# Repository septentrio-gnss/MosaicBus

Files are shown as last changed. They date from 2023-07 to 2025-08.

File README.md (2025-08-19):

<p align="center">
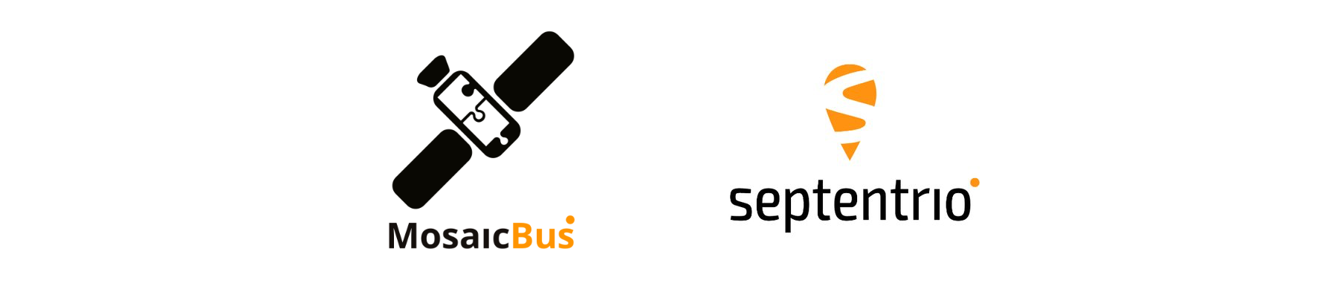
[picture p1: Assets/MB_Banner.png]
  
</p>

# MosaicBus

## What is the MosaicBus project?
**MosaicBus is a Septentrio Open-Source hardware project powered by the Mosaic GNSS receiver that is compatible with the Mikroe mikroBUS standard.**
The objective of this project was to allow easy prototyping and development with the Mosaic by using the mikroBUS ecosystem.

The board also has the option to be used as a standalone device by using the USB-C connector and MosaicBus has been designed to be used with either the Septentrio [**Mosaic-x5**](https://www.septentrio.com/en/products/gps/gnss-receiver-modules/mosaic-x5) or the [**Mosaic-H**](https://www.septentrio.com/en/products/gps/gnss-receiver-modules/mosaic-h).

<p align="center">
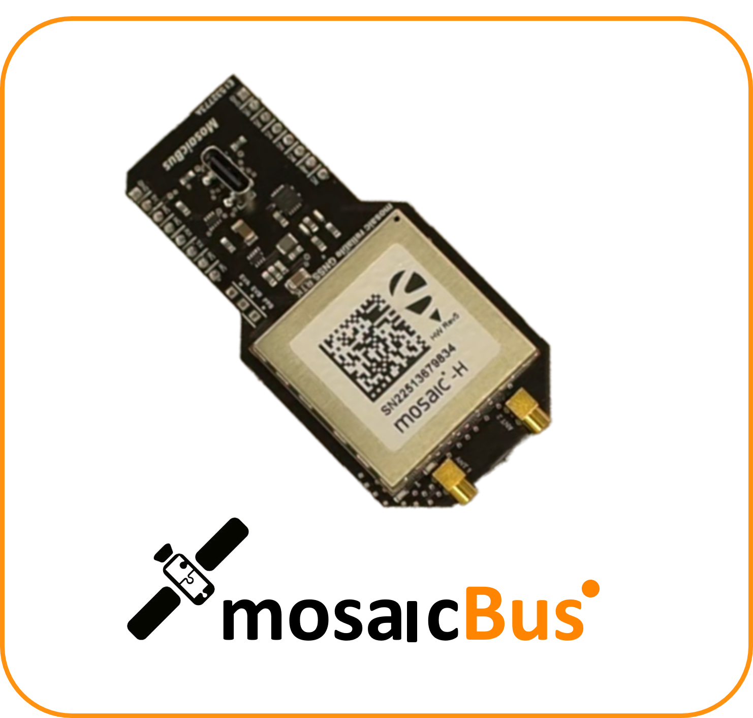
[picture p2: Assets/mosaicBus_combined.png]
  
</p>

## What is the Mosaic module?
**[Mosaic modules](https://web.septentrio.com/GH-SSN-modules) are Septentrio's small-size and low-power GNSS receiver modules ideal for providing highly accurate positions.** Mosaic modules integrate the latest generation of GNSS technology, delivering highly accurate positions with minimal power consumption. While compact in size they fully retain the high-reliability and exceptional accuracy performance that Septentrio receivers are known for. True multi-frequency multi-constellation technology gives our module receivers access to every possible signal from all available GNSS satellite constellations including the U.S. GPS, European Galileo, Russian GLONASS, as well BeiDou, QZSS and NavIC. [Septentrio’s advanced field-proven algorithms](https://www.septentrio.com/en/company/septentrio-gnss-technology) exploit this signal diversity to deliver maximum positioning availability and reference network compatibility.

## Can I buy this board?
### Similar board produced by MIKROE
While an exact version of this board cannot be bought today. A very similar board is now sold and distributed by MIKROE (MikroElektronika). MIKROE is a Serbian company known for its mikroBUS™ standard and Click board™ ecosystem, which simplify embedded development. In collaboration with Septentrio, they created the Mosaic Click board (originally using this project as an inspiration), integrating Septentrio’s mosaic-X5 GNSS module into the mikroBUS platform. This brings cm-level RTK positioning, anti-jamming/anti-spoofing resilience, and multi-constellation support to developers, enabling fast prototyping and easy integration of high-precision GNSS into applications ranging from hobby projects to robotics, IoT, and industrial systems.

You can purchase this Mikroe board here:
[**Mikroe mosaic Click board**](https://www.mikroe.com/mosaic-click)

<p align="center">
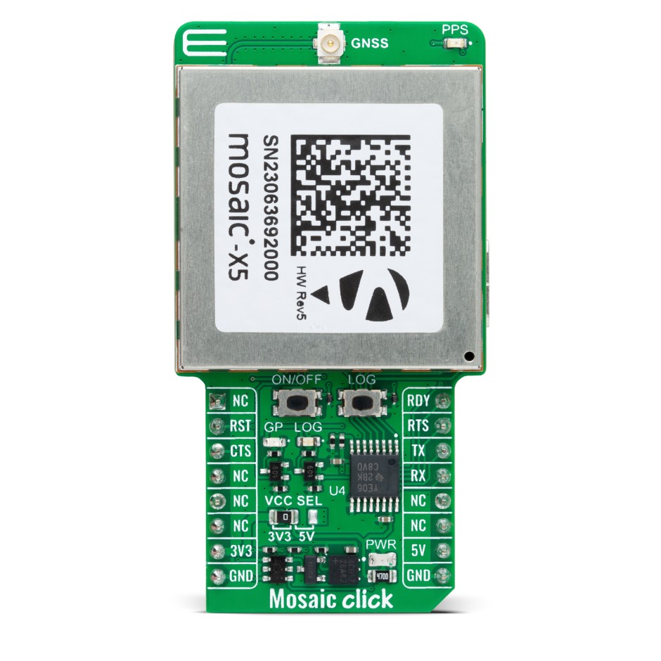
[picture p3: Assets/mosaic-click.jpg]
  
</p>

### Mikroe (and MosaicBus) boards usable with Movella XSense
Mikroe board (or a MosaicBus board), such as the Mosaic Click board, can bring high-precision GNSS into the Movella Xsens ecosystem, enabling seamless fusion of GNSS and inertial sensors. By pairing the Mosaic Click with Xsens’ MTi-series IMUs or GNSS/INS devices, users can achieve robust centimeter-level positioning with enhanced resilience against jamming and spoofing. This combination is ideal for applications in robotics, UAVs, autonomous systems, and industrial navigation, where accurate and reliable positioning depends on both inertial sensing and high-end GNSS. The boards, based on Mikroe’s mikroBUS™ standard, ensure easy integration and rapid prototyping, making them suitable for both research and commercial development.

You can get an evaluation kit from Movella XSense here:
[**Movella XSense mosaic eval kit**](https://www.movella.com/products/sensor-modules/xsens-mti-680-septentrio-mosaic-x5)
<p align="center">
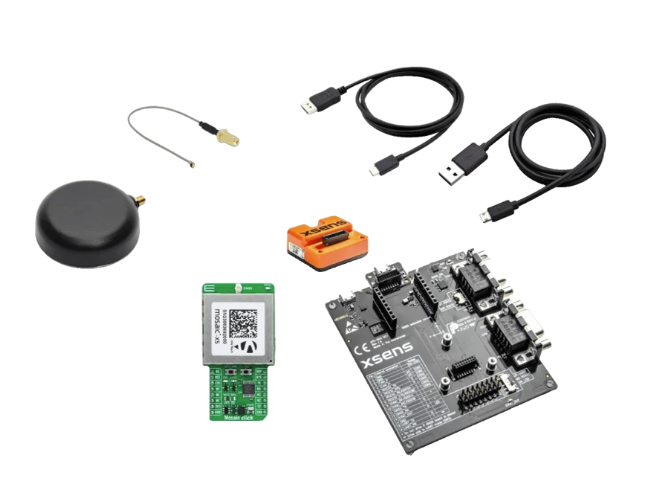
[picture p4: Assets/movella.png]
  
</p>

### Who is Septentrio?
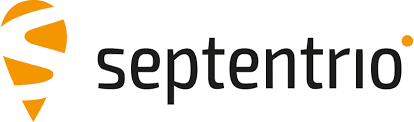
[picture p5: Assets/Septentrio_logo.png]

Septentrio designs, manufactures and sells high-precision, multi-frequency, multi-constellation GPS/GNSS equipment for use in demanding applications. Septentrio products are used in a wide variety of industries including marine, construction, precision agriculture, logistics, machine control, rail, automotive, survey and mapping, geographic information systems (GIS), unmanned aerial vehicles (UAVs) and scientific. Septentrio receivers deliver consistently accurate and precise GNSS positioning scalable to centimeter-level and designed to perform solidly in the most challenging environments. Septentrio receivers are available as OEM boards, housed receivers and smart antennas.

The technology offers high accuracy and reliability thanks to GNSS+ algorithms as well as <a href="https://www.septentrio.com/en/advanced-interference-monitoring-mitigation-aim">Septentrio's Advanced Interference Monitoring and Mitigation (AIM+)</a> which protects against RF interference (jamming) and spoofing.

For more information about Septentrio products go to [**https://www.septentrio.com/**](https://web.septentrio.com/GH-SSN-home).

## How to set up MosaicBus?
### Hardware
To start using the MosaicBus some antennas need to be connected to the board.
When using a [**Mosaic-x5**](https://www.septentrio.com/en/products/gps/gnss-receiver-modules/mosaic-x5) only a single antenna needs to be connected to the ANT 1 MMCX connector.
However when using the [**Mosaic-H**](https://www.septentrio.com/en/products/gps/gnss-receiver-modules/mosaic-h) a single or dual antenna setup can be configured.
To have a single antenna setup the antenna needs to be connected to the ANT 1 MMCX connector.
When using dual antennas the main antenna is connector to the ANT 1 MMCX connector while the auxillary is connected to the ANT 2 MMCX connector.

Afterwards just click the MosaicBus into a mikroBUS compatible carrier board.

The easiest way to configure the Mosaic is through the USB interface.
When connecting the MosaicBus with a computer through a USB-C cable. 
A new USB device should be visible on the system.
If the system is running Linux or MacOS, the drivers for the Mosaic are automatically installed.
When using a Windows system the drivers have to be installed manually.
These are contained on the new drive visible in file manager.
Running the installer is unnecessary when [**RxTools**](https://www.septentrio.com/en/products/gps-gnss-receiver-software/rxtools) is already installed.

## Interfaces on the MosaicBus
The MosaicBus is compliant with the mikroBUS standard.
<p align="center">
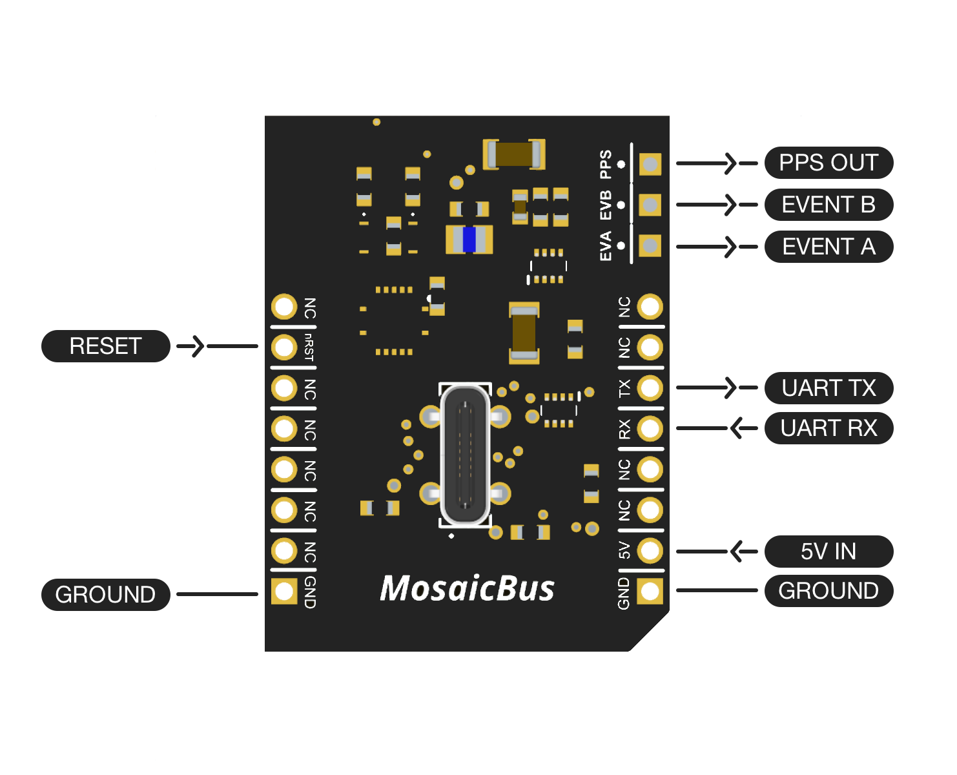
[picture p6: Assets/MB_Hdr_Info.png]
  
</p>

### Power
In order to power the board there are 2 options.
The first is to use the USB-C connector.
Another option is to use the +5V and ground pins.
This can be powered by any 5V DC supply.

### RESET
To reset the MosaicBus board the nRST pin can be pulled low.
This for example can be done by a GPIO pin or a button.

### COM port
To communicate with the Mosaic a **UART** connection is exposed.
This can be used with a serial reader or a microcontroller.
The following settings are required for this communication to take place.
| baud rate | data bits | stop bits | parity | flow control |
|:---:|:---:|:---:|:---:|:---:|
| 115200 | 8 | 1 | no | none |

On the Mosaic if some settings need to be changed, the ones for *COM3* are the ones exposed and should be edited.

### USB
#### Web interface
By default the Mosaic suppports **Ethernet-over-USB**. Therefore its possible to connect to the receiver and access its information and configuration through a browser.
To do so search to the static IP address which is [`192.168.3.1`]().
This will show the Mosaic's web interface where you can configure the Mosaic.

#### Command line
Another way to connect to the Mosaic receiver is using its COM ports.
These ports should be visible as [`ACM0`]() and [`ACM1`]().
Using a serial terminal such as Putty a connection can be established using the following settings.
| port | baud rate | data bits | stop bits | parity | flow control |
|:---:|:---:|:---:|:---:|:---:|:---:|
| ACM0 / ACM1 | 115200 | 8 | 1 | no | none |

Now you can interface using the command line.
For information on the commands, syntax and reponses the Mosaic Reference Guide section 3.1 can be consulted.

### Events
The MosaicBus has through hole pins which expose 2 event pins. **EVENT A** and **EVENT B**
These can be used to input a time-tagged signal with an accuracy of 20ns.
In turn this will output SBF with can include the position and/or time when the event occurs.
This can be configured using the **setEventParameters** command.

### PPS
The board also exposes a **PPS** output through hole pin.
The polarity, frequency and pulse width of this can be set with the **setPPSParameters** command.
The PPS signal uses 1.8V logic, but can be level-shifted to 3.3V logic if required.

### Antennas 
<p align="center">
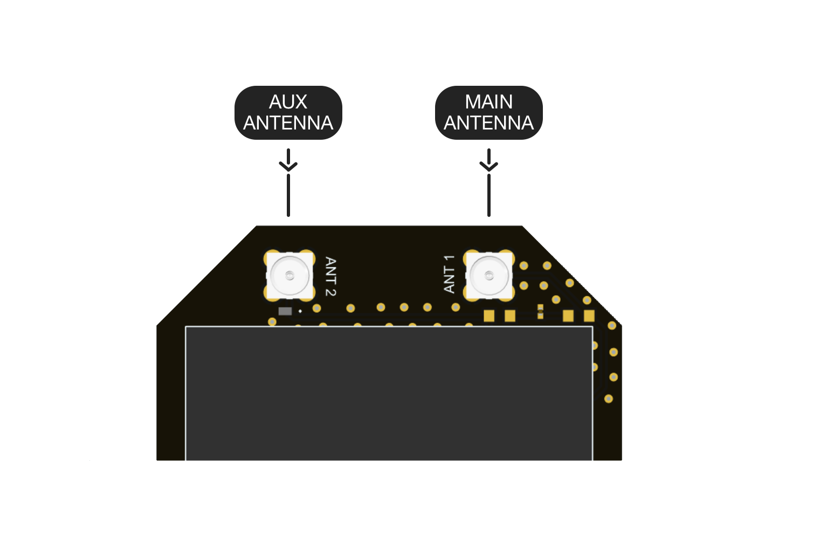
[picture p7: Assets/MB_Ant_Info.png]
  
</p>

The MosaicBus also has 1 or 2 antenna connectors available depending if you used the Mosaic-x5 or Mosaic-H model.
When using the [**Mosaic-x5**](https://www.septentrio.com/en/products/gps/gnss-receiver-modules/mosaic-x5) the **ANT 1** will be available to use.
When using the [**Mosaic-H**](https://www.septentrio.com/en/products/gps/gnss-receiver-modules/mosaic-h) both the **ANT 1** and **ANT 2** are available to provide dual heading.
*This has to be configured in the Mosaic*

## How to produce
All the files needed are each in their own folder, such as the BOM (Bill Of Materials), the Gerber and Pick-place files.

***Disclamer***
All the files are provided as is. These have not been fully validaded by the author or Septentrio.
The use of any of these files are at your own risk and responsibility.

---
*Designed by A. Gheeraert*

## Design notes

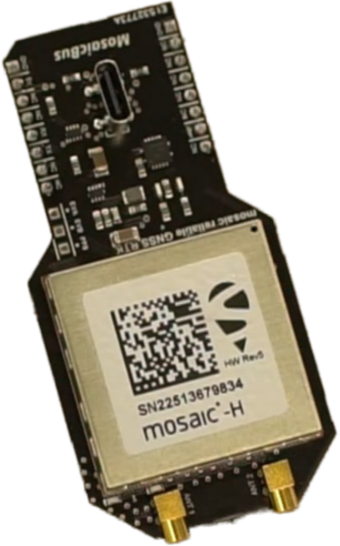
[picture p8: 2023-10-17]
Assets/design-b1985c28-233e-4ac5-8a65-0dd0d61b1b28.png

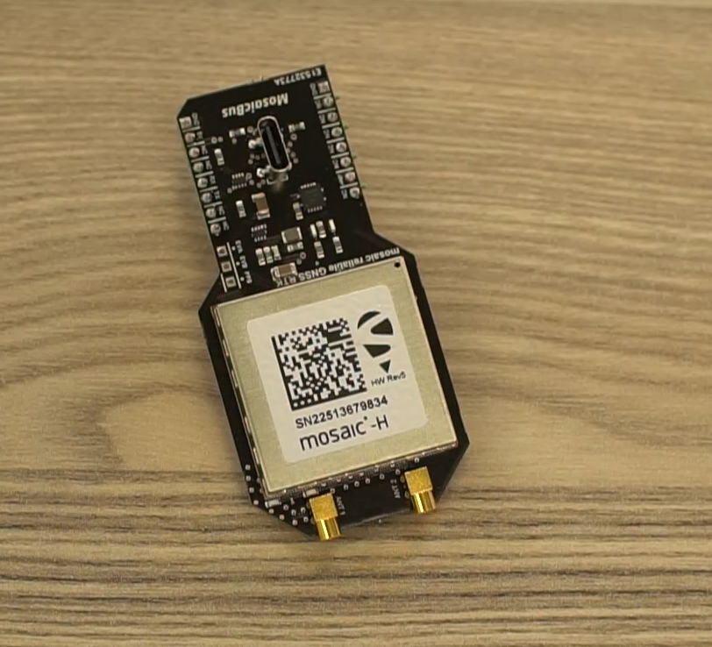
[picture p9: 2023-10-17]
Assets/mosaicBus.PNG

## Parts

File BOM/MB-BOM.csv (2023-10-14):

Reference:
Date: | Thu Jul 06 2023 11:54:32 GMT+0200 (Central European Summer Time)
Generated by: | Eurocircuits PCBA Visualizer
Reference designators | Quantity | MPN | Manufacturer | Description
C1 | 1 | MC0201N101J250CT | Multicomp | SMD Multilayer Ceramic Capacitor, 0201 [0603 Metric], 100 pF, 25 V, ± 5%, C0G / NP0, MC Series
C2 | 1 | 0805X226K6R3CT | Walsin | Multilayer Ceramic Capacitors MLCC - SMD/SMT 0805 MLCC X5R 22 uF +/- 10% 6.3 V T&amp;R GP
C3, C4 | 2 | 1206X226K160CT | Walsin | SMD Multilayer Ceramic Capacitor, 1206 [3216 Metric], 22 µF, 16 V, ± 10%, X5R
C5 | 1 | 0603N100F101CT | Walsin | Capacitor: ceramic; MLCC; 10pF; 100V; C0G; ±1%; SMD; 0603
D1 | 1 | TPD1E0B04DPYR | Texas Instruments | 19V Clamp 1.7A (8/20µs) Ipp Tvs Diode Surface Mount 2-X1SON (1x.60)
D2, D4 | 2 | 155060AS75300 | Wurth | Amber 605nm LED Indication - Discrete 2V 2-SMD, No Lead
D3 | 1 | TPD2E2U06QDCKRQ1 | Texas Instruments | 12.4V (Typ) Clamp 5.5A (8/20µs) Ipp Tvs Diode Surface Mount SC-70-3
J1 | 1 | USB4120-03-C | GCT | USB-C (USB TYPE-C) USB 2.0 Receptacle Connector 24 (16+8 Dummy) Position Surface Mount, Through Hole
J2, J3 | 2 | 825433-8 | TE Connectivity / AMP | 8 Positions Header, Unshrouded, Breakaway Connector 0.100" (2.54mm) Through Hole Gold
J4, J5 | 2 | MMCX6252N1-3GT30G-50 | Amphenol | Rf / Coaxial Connector, Mmcx Coaxial, Right Angle Jack, Through Hole Right Angle, 50 Ohm
L1, L2 | 2 | 744786139A | Wurth Elektronik | 39nH Unshielded Multilayer Inductor 400mA 700mOhm Max 0603 (1608 Metric)
L3 | 1 | 744383430047 | Wurth | Size 2010; L = 0.47 µH ±30%; IR = 2.3 A; Isat = 5.25 A; RDCmax = 63 mΩ
R1, R2 | 2 | WR06X5101FTL | Walsin | RESISTOR, THICK FILM, 5K1, 1%, 75V, 0603
R5, R7 | 2 | WR06X104 JTL | Walsin | SMD Chip Resistor, 0603 [1608 Metric], 100 kohm, WR06 Series, 75 V, Thick Film, 100 mW
R6 | 1 | WR06X223 JTL | Walsin | 22 kOhms ±5% 0.1W, 1/10W Chip Resistor 0603 (1608 Metric) Thick Film
U1 | 1 | mosaic-X5 | Septentrio Inc. | Mosaic Hardware Manual
U2 | 1 | KCZ1210AH900HRTD25 | TDK Corporation | 2 Line Common Mode Choke Surface Mount 90 Ohms @ 100 MHz 100mA DCR 1.75Ohm
U3 | 1 | TPS2116DRLR | Texas Instruments | 1.6-V to 5.5-V, 40-mΩ, 2.5-A, low-IQ, priority power multiplexer
U4 | 1 | TPS628501DRLR | Texas Instruments | Buck Switching Regulator IC Positive Adjustable 0.6V 1 Output 1A SOT-583
U5 | 1 | SN74LVTH125RGYRG4 | Texas Instruments | SMD IC 74LVTH125RGYP QFN14
R3, R4, R8, R9 | 4 | WR06X103JTR | Walsin | 10kOmh resistor
R10, R11 | 2 | WR06X331JTR | Walsin | 330Ohm resistor

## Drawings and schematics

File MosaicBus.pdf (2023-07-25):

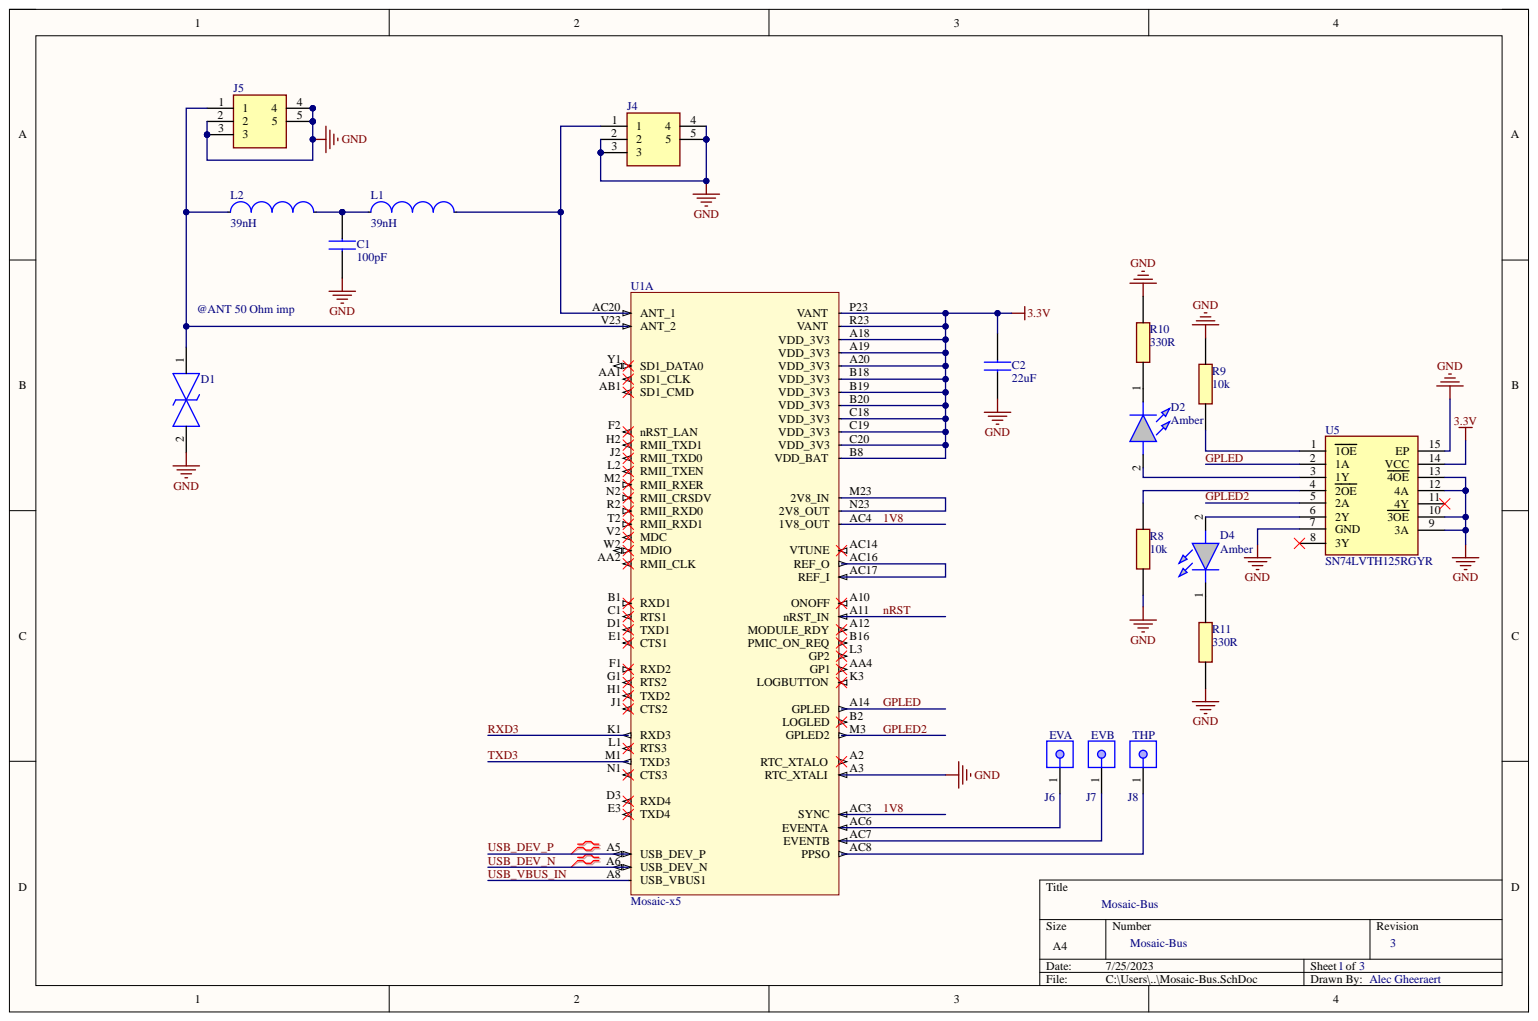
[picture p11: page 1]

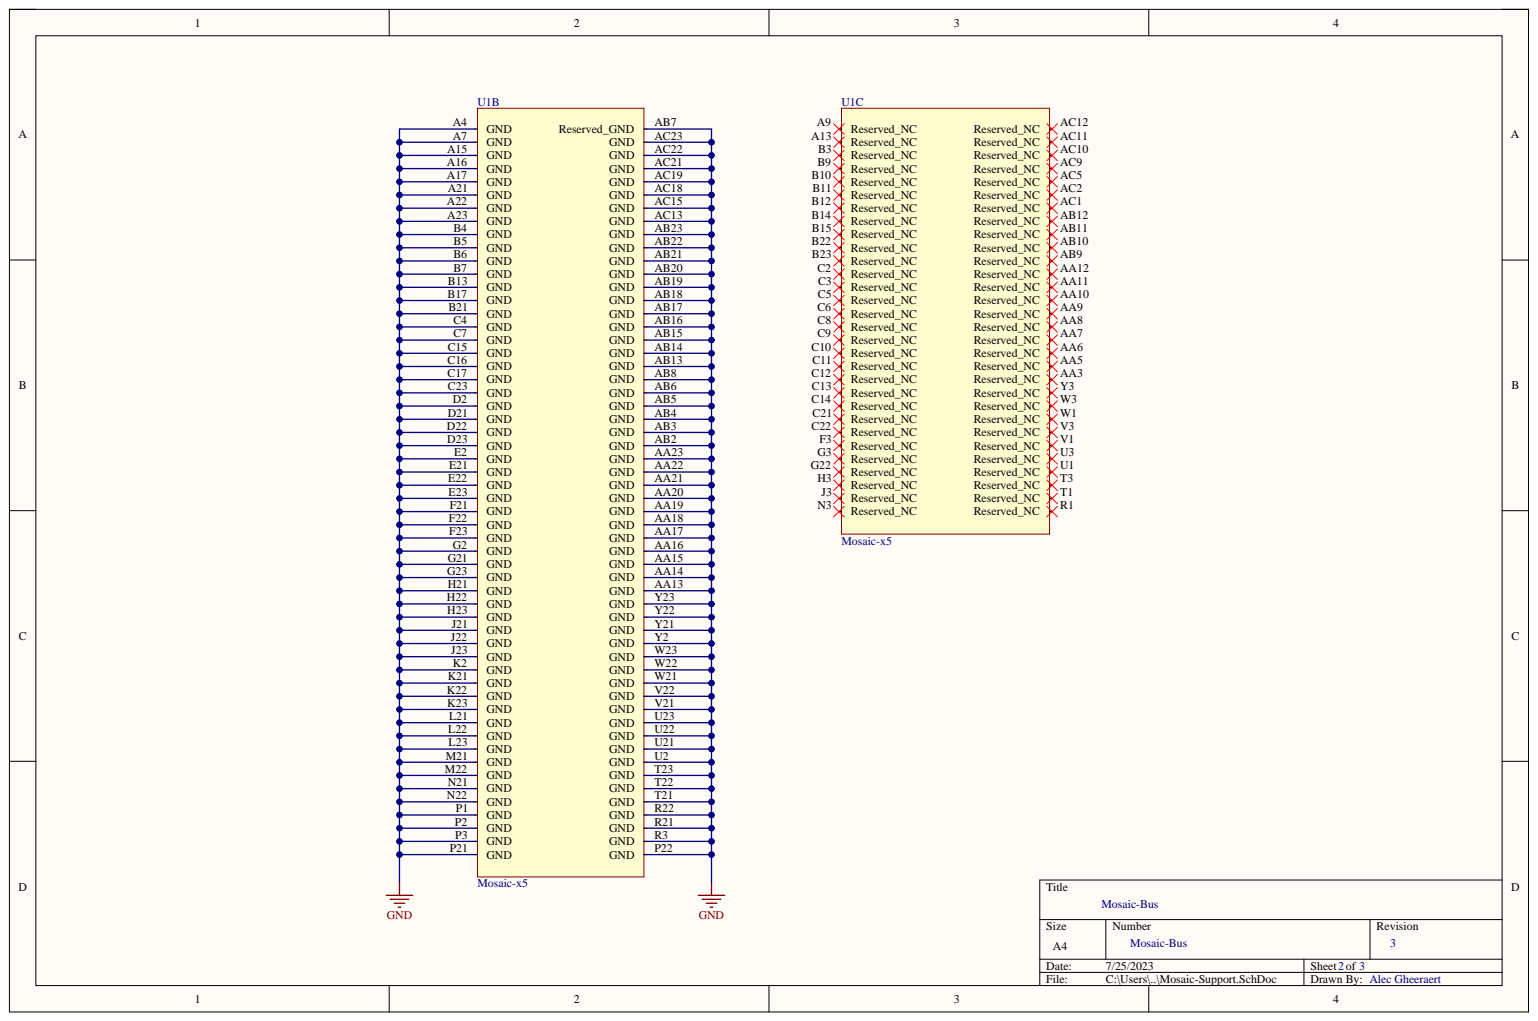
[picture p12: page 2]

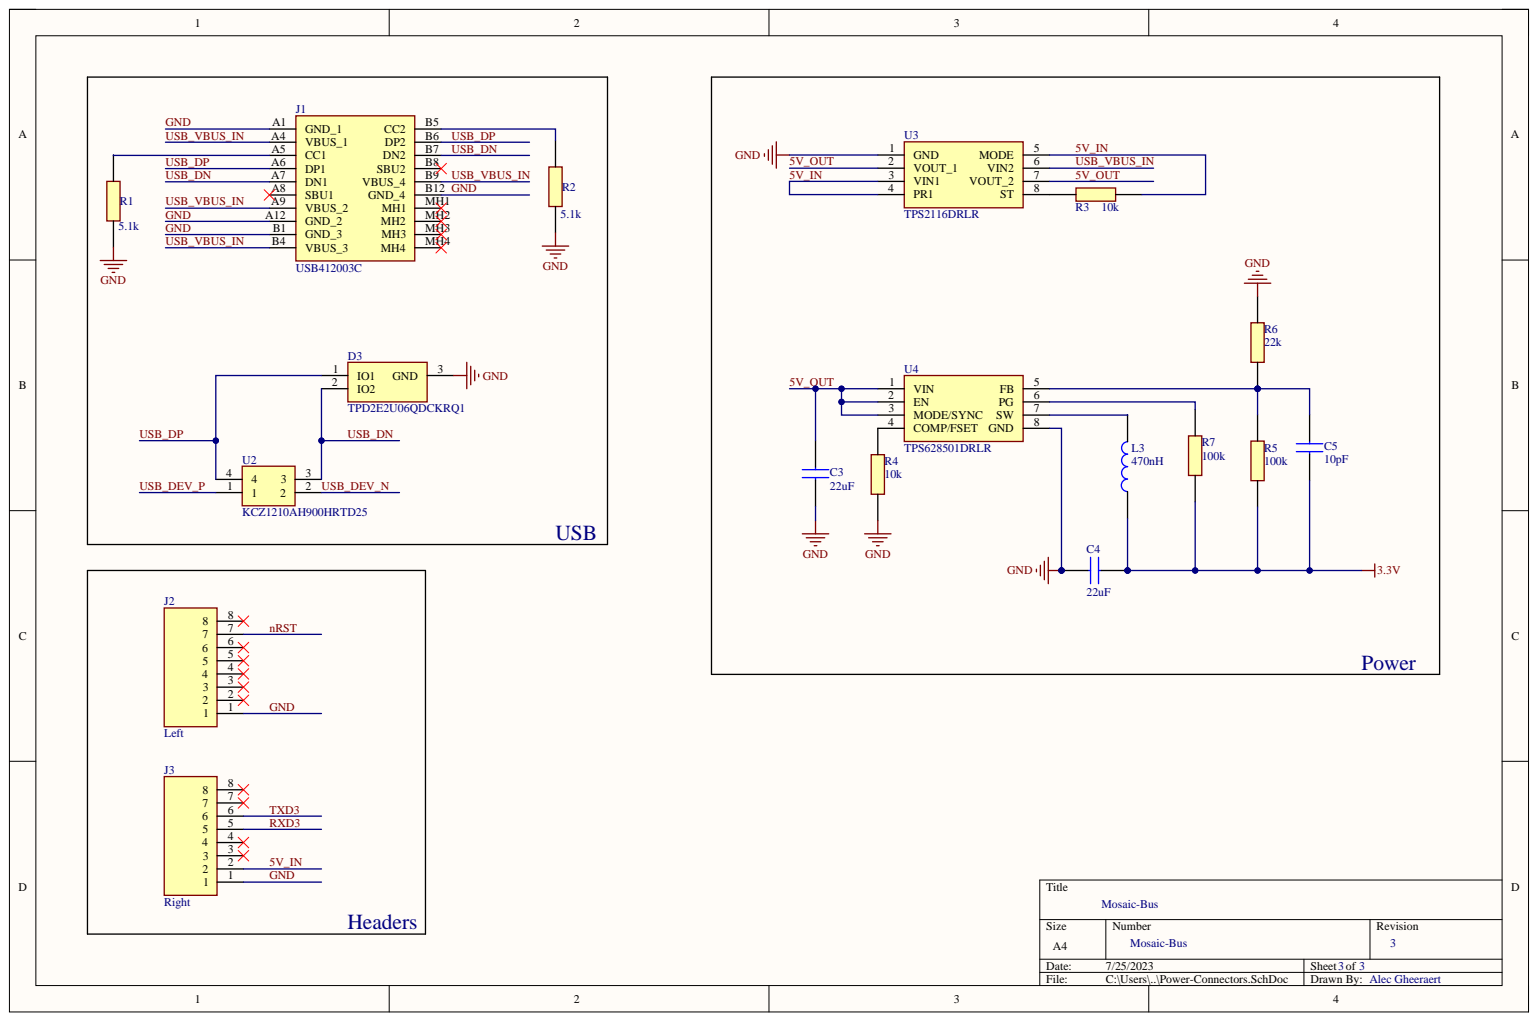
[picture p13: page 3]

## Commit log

2023-10-09 Antenna info
2023-10-14 File updates
    [MB-Connectors.SchDoc, MB-Pick-Place.csv, MB-Support.SchDoc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]
2023-10-17 New pictures
    New board pictures
